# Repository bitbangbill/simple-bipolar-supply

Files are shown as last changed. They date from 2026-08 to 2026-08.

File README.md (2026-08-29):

# Simple Bipolar Supply

The simple bipolar supply is a USB-C powered dual channel (positive and negative) power supply. The module is a drop in system for projects requiring a bipolar suppy. The project is designed to be a series of building blocks a tailored supply for any application.

## Gallery

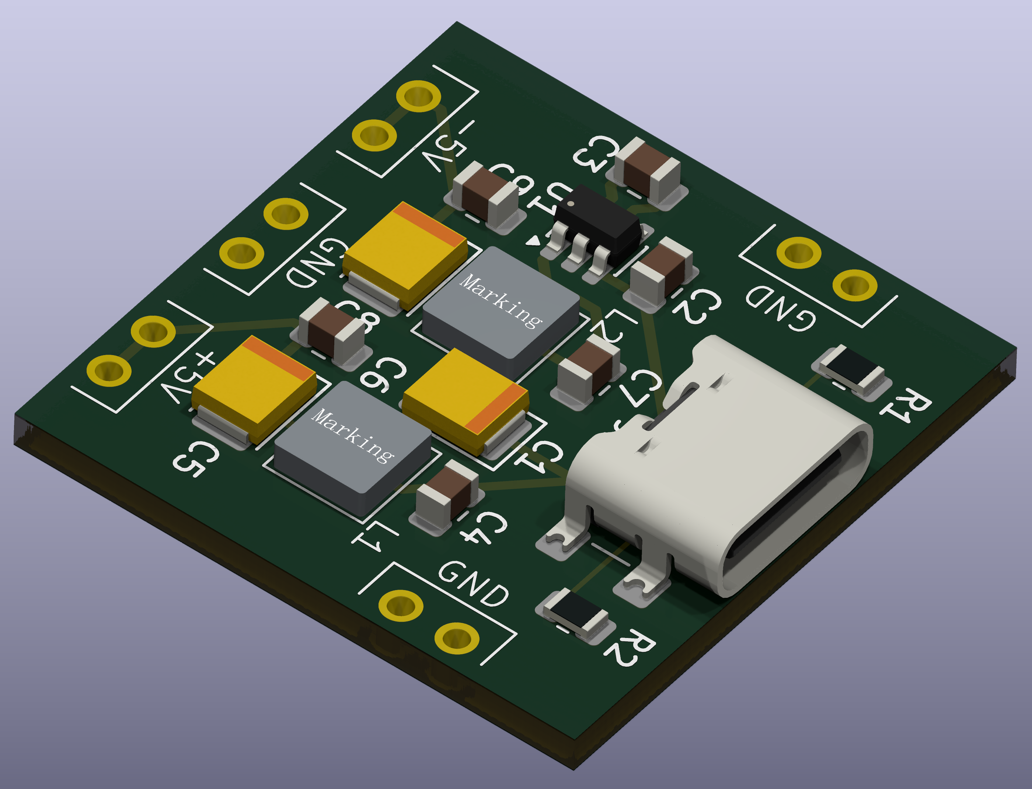
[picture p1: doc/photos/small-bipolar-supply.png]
PCB Render

*Revision B of the charge-pump variant rendered in KiCad*

## Features

### Generic
* USB-C powered.
* Dual channel +/- with respect to ground.
* Filtered output.
* Pin pitch designed for breadboard compatibility.
* Pi filtered output.

## Status : Prototype phase
### Issues
* None so far! 🤞

### In The Works
* Initial proof of concept for the charge pump variant of the suppy.
* PCB and parts order on the way for testing RevA.
* Regulated and adjustable output stage for the lower voltage version.

### Roadmap
The long term plan is to develop multiple building blocks for two primary variants of the power supply. The building blocks and whole system are outlined in the system block diagram. Only the first two blocks are implemented in the first revision. Each block in the diagram between USB-C and output can be added and removed as necesary.

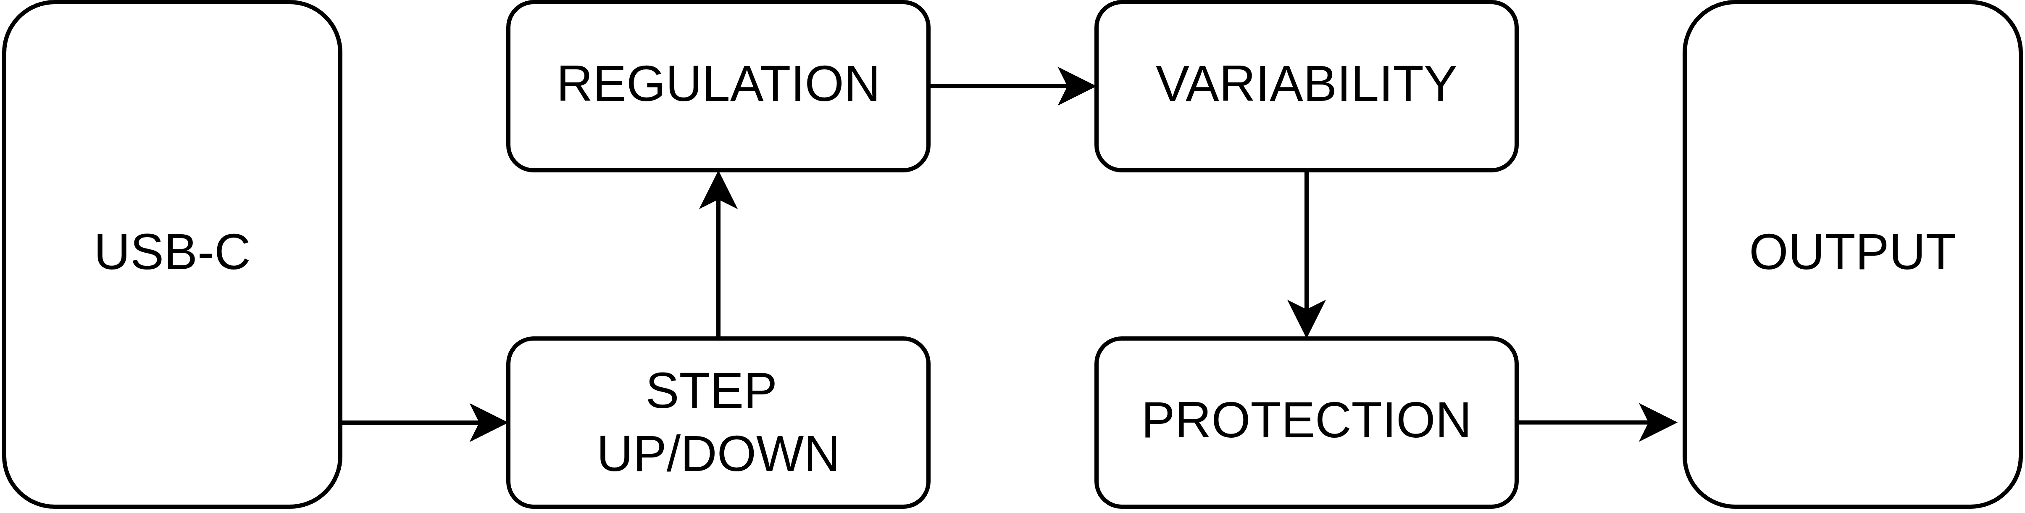
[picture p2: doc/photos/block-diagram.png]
System Block diagram

*Block diagram convering the project roadmap*

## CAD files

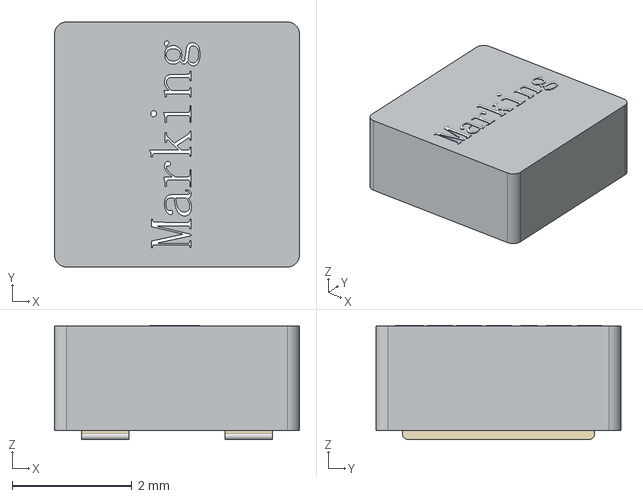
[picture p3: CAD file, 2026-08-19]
electrical/3d/SRP4020FA.stp
4.10 x 4.10 x 1.91 mm

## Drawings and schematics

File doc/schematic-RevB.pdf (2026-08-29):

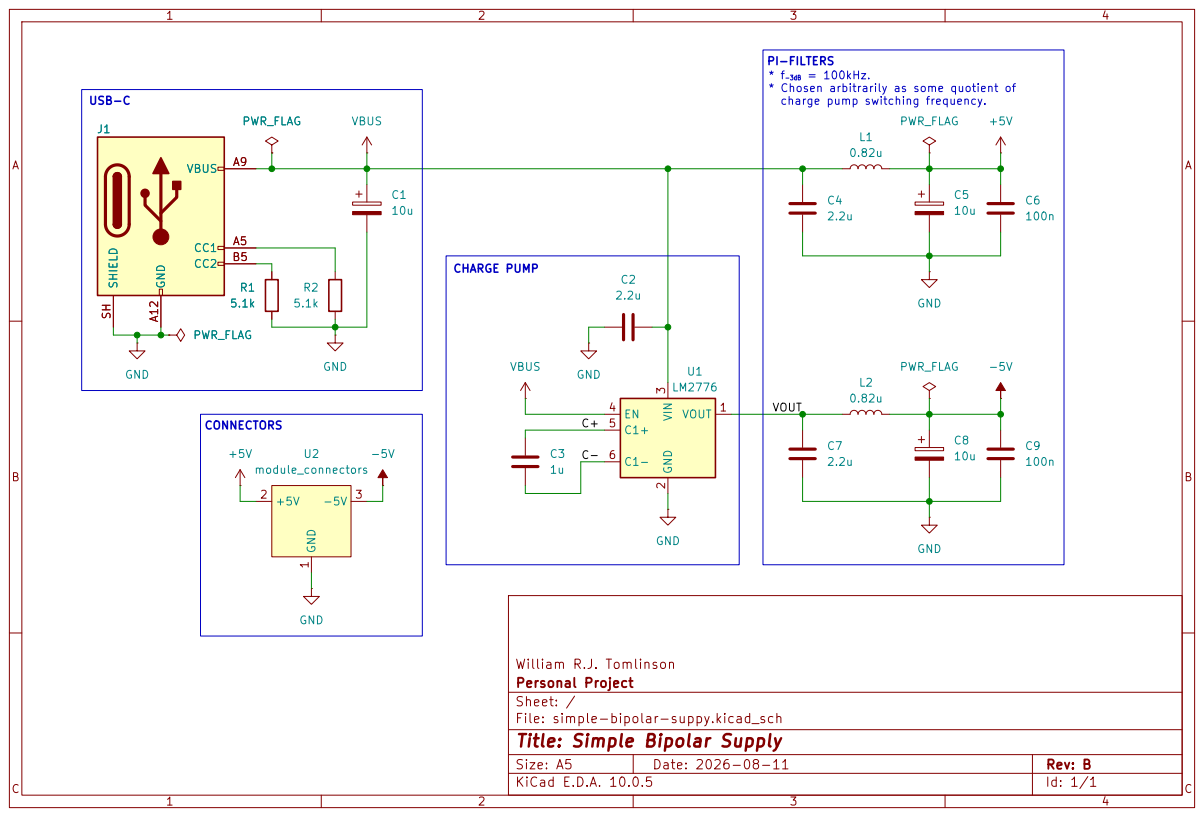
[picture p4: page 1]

William R.J. Tomlinson
Personal Project
Sheet: /
File: simple-bipolar-suppy.kicad_sch
Title: Simple Bipolar Supply

Size: A5 | Rev: B | C Date: 2026-08-11
KiCad E.D.A. 10.0.5 | Id: 1/1

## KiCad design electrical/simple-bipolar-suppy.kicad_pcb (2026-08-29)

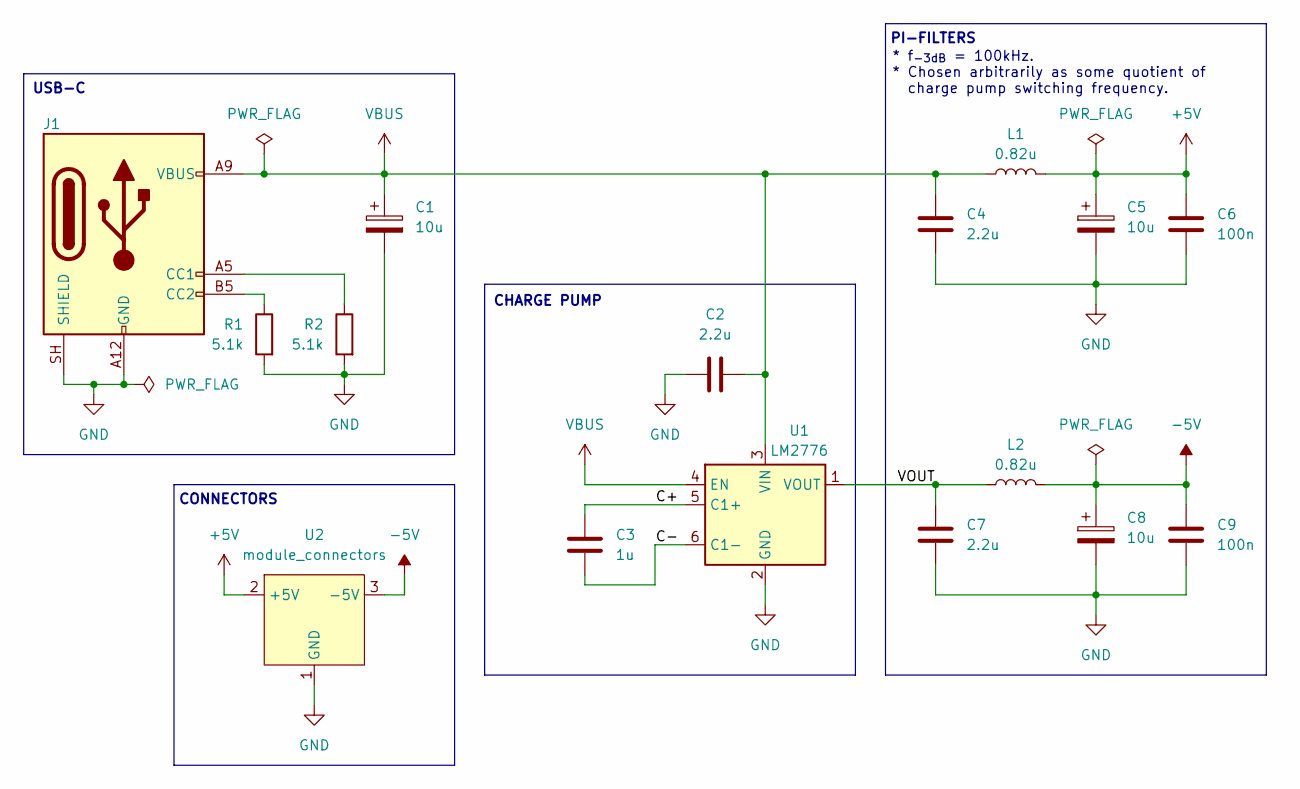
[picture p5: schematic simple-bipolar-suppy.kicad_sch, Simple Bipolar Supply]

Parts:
C1, C5, C8: 10u; CP_EIA-3528-12_Kemet-T
C2, C4, C7: 2.2u; C_0805_2012Metric
C3: 1u; C_0805_2012Metric
C6, C9: 100n; C_0805_2012Metric
J1: USB_C_Receptacle_PowerOnly_6P; USB_C_Receptacle_GCT_USB4135-GF-A_6P_TopMnt_Horizontal
L1, L2: 0.82u; SRP4020
R1, R2: 5.1k; R_0805_2012Metric
U1: LM2776; SOT-23-6
U2: module_connectors; module-footprint

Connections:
+5V: C5.1, C6.1, L1.2, U2.2 (+5V)
-5V: C8.1, C9.1, L2.2, U2.3 (-5V)
/C+: C3.2, U1.5 (C1+)
/C-: C3.1, U1.6 (C1-)
/VOUT: C7.1, L2.1, U1.1 (VOUT)
GND: C1.2, C2.1, C4.2, C5.2, C6.2, C7.2, C8.2, C9.2, J1.A12 (GND), J1.B12 (GND), J1.SH (SHIELD), R1.2, R2.2, U1.2 (GND), U2.1 (GND)
unnamed: J1.A5 (CC1), R2.1
unnamed: J1.B5 (CC2), R1.1
VBUS: C1.1, C2.2, C4.1, J1.A9 (VBUS), J1.B9 (VBUS), L1.1, U1.3 (VIN), U1.4 (EN)

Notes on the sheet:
* f_{-3dB} = 100kHz. * Chosen arbitrarily as some quotient of charge pump switching frequency.
PI-FILTERS
CONNECTORS
CHARGE PUMP
USB-C

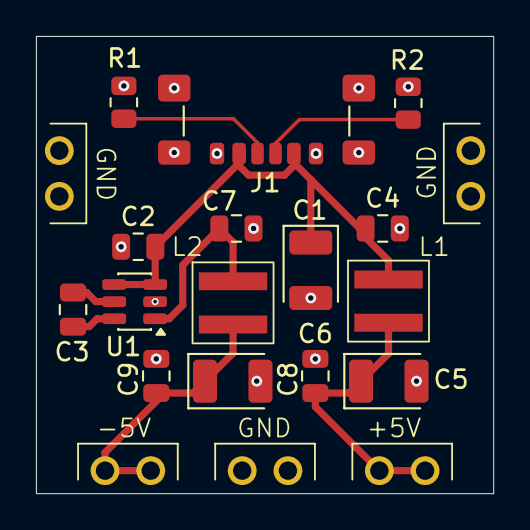
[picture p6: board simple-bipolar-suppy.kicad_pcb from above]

Board: 2 copper layers, 25.4 x 25.4 mm, 16 parts (0 on the bottom side), 9 nets.

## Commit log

2026-08-19 chore: initialised kicad .gitignore
2026-08-19 feat: RevA schematic completed
    [small-bipolar-supply.kicad_pcb, small-bipolar-supply.kicad_sch]
2026-08-19 chore: added connectors to schematic for castellated edges
    [small-bipolar-supply.kicad_sch]
2026-08-19 chore: castellated footprints and inductor 3d model
    [SRP4020FA.stp]
2026-08-19 feat/wip: first revision of pcb component placement
    [small-bipolar-supply.kicad_pcb]
2026-08-19 chore: PCB pin spacing optimised for breadboard use
    [small-bipolar-supply.kicad_pcb]
2026-08-19 feat/done: tuned component layout and silkscreen
    [small-bipolar-supply.kicad_pcb]
2026-08-19 trace layout complete
    [small-bipolar-supply.kicad_pcb, small-bipolar-supply.kicad_sch]
2026-08-19 branding and final tweaks
    [small-bipolar-supply.kicad_pcb]
2026-08-28 feat: new module symbol and footprints
    [small-bipolar-supply.kicad_pcb]
2026-08-28 Removed castellated edges & various layout tweaks
    [small-bipolar-supply.kicad_pcb, small-bipolar-supply.kicad_sch]
2026-08-28 updating revision letter
    [small-bipolar-supply.kicad_pcb, small-bipolar-supply.kicad_sch]
2026-08-29 various structure and documentation changes
    [SRP4020FA.stp, simple-bipolar-suppy.kicad_pcb, simple-bipolar-suppy.kicad_sch]
